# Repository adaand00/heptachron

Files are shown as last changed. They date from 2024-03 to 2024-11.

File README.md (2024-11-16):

```
    __  ____________  _________   ________  ______  ____  _   __
   / / / / ____/ __ \/_  __/   | / ____/ / / / __ \/ __ \/ | / /
  / /_/ / __/ / /_/ / / / / /| |/ /   / /_/ / /_/ / / / /  |/ / 
 / __  / /___/ ____/ / / / ___ / /___/ __  / _, _/ /_/ / /|  /  
/_/ /_/_____/_/     /_/ /_/  |_\____/_/ /_/_/ |_|\____/_/ |_/   
```                                                                
## Heptachron - 7 segment LED wrist watch
Latest prototype:


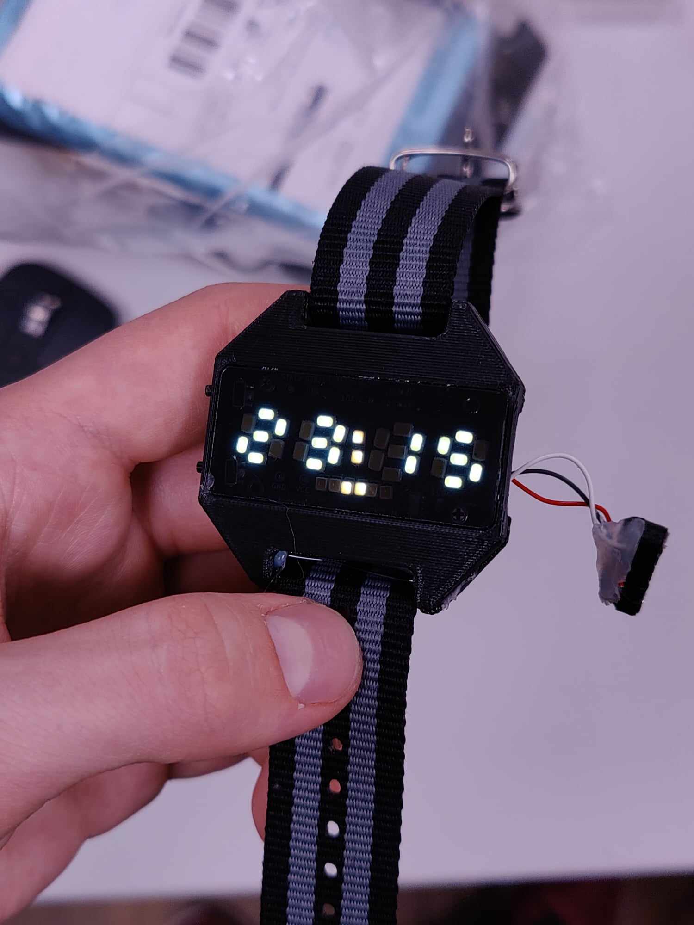
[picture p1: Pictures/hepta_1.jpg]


### Concepts and ideas
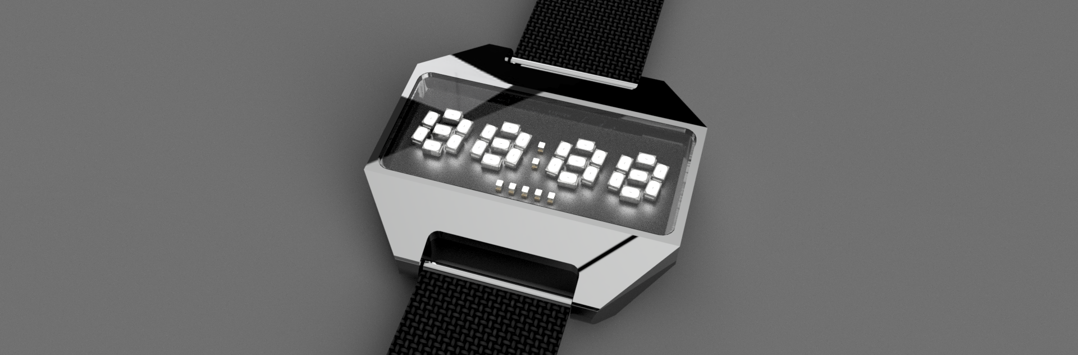
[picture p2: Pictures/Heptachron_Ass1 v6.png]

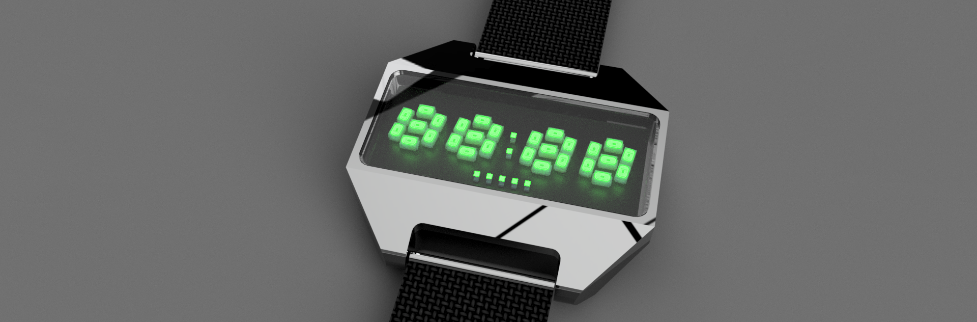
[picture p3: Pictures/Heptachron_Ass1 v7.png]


### Features
 - [x] 4 digits (hours and minutes)
 - [x] Seconds displayed in binary (6 bits)
 - [x] Always-on display
 - [x] Rechargeable battery
 - [x] Magnetic charger
 - [ ] Long battery life
 - [x] Megatron
 - [x] Not waterproof
 - [ ] Very accurate

### Contributors
Adam Anderson: Electronics, programming

Gustav Abrahamsson: Electronics, mechanical design

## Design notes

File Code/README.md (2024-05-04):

Functions:

 - View time / Set time
 - View battery / turn off
 - View brightness / set brightness
 - (View alarm / set alarm)
 - (View 24H/12H mode / set 24H/12H mode)

Use `NEXT` button to go to next function. Then press `SET` button to interact
with function. If no button is pressed for some time, the time will be displayed
again. Hold both buttons to turn off.

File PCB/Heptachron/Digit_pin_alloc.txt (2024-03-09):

CS:n  -   Current sink 'n', one for each digit       [CATHODE]
                                                              
SW:n  -   Switch power source, one for each segment  [ANODE]  
               SW1: A, SW2: B, ..., SW7: G                    

                          ┌─┬───┐                             
                          │◄│A  │                             
                          └─┴───┘                             
                   ┌───┐           ┌─▲─┐                      
                   │   │           ├───┤                      
                   │ F │           │ B │                      
                   ├───┤           │   │                      
                   └─▼─┘  ┌─┬───┐  └───┘                      
                          │◄│G  │                             
                   ┌───┐  └─┴───┘  ┌─▲─┐                      
                   │   │           ├───┤                      
                   │ E │           │ C │                      
                   ├───┤           │   │                      
                   └─▼─┘           └───┘                      
                          ┌─┬───┐                             
                          │◄│D  │                             
                          └─┴───┘

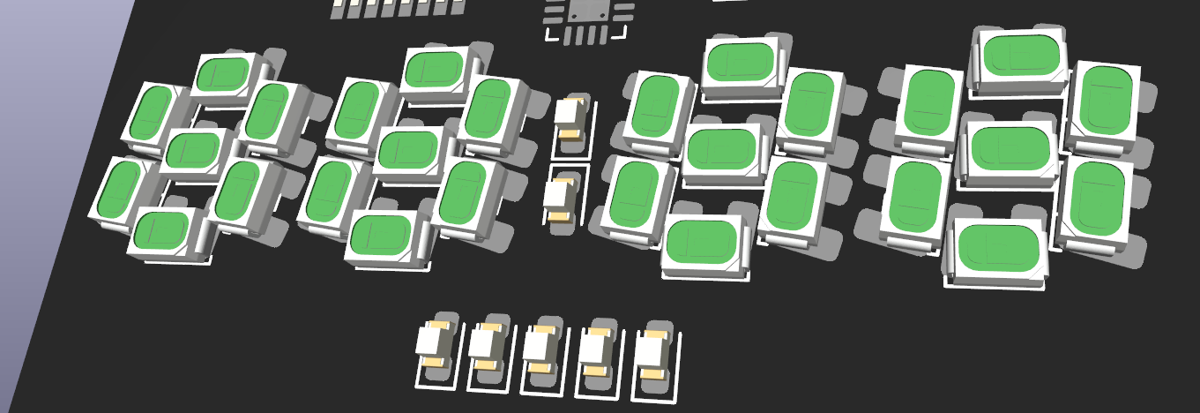
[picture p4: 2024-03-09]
Pictures/PCB_concept.png

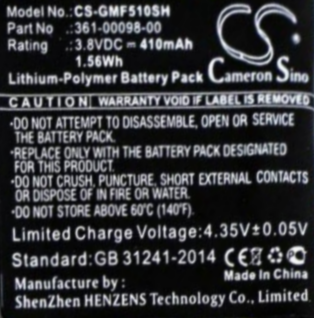
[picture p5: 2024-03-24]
Pictures/Battery_label.png

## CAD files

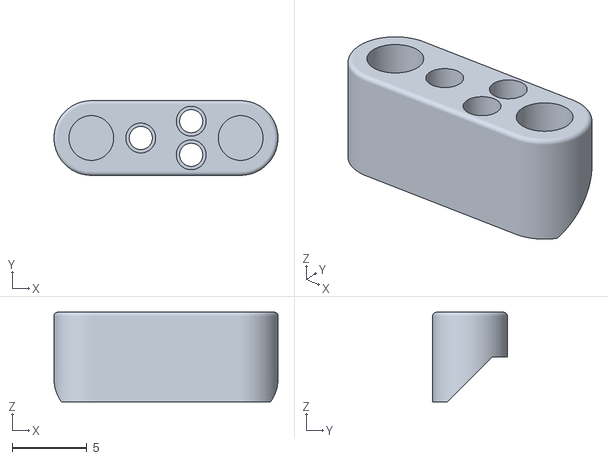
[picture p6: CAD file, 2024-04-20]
CAD/Pre/Female_heptachronnector.stl
15.0 x 5.00 x 6.00

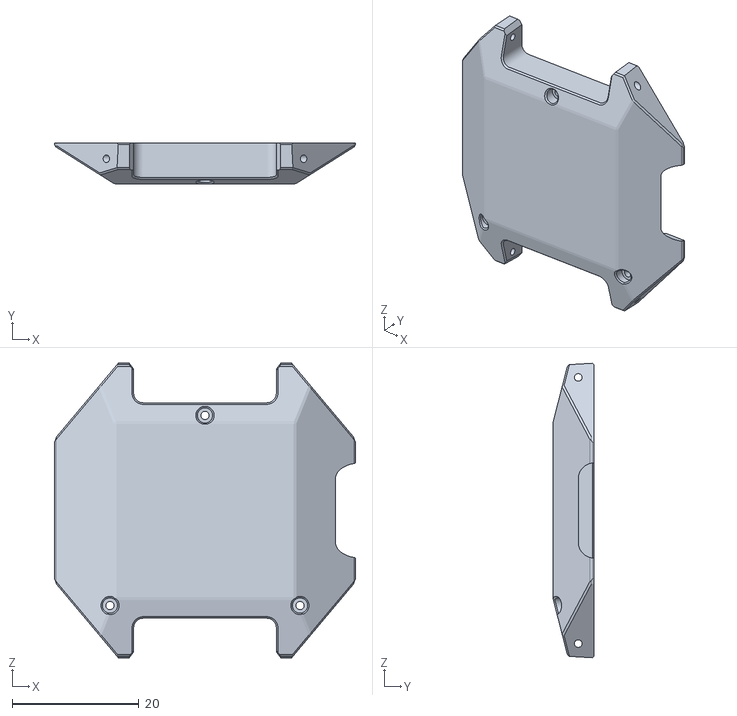
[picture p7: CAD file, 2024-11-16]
CAD/v2/Case_bottom.stl
47.5 x 6.50 x 46.5

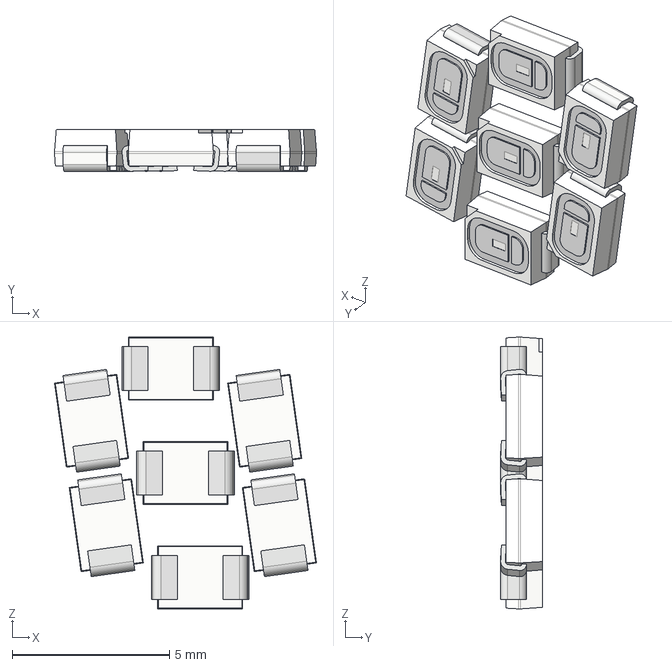
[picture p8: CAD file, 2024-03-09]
PCB/3D_Files/Cree_LED/Cree_Digit.step
8.32 x 1.32 x 8.63 mm
Cree_Green_PLCC2 x 7

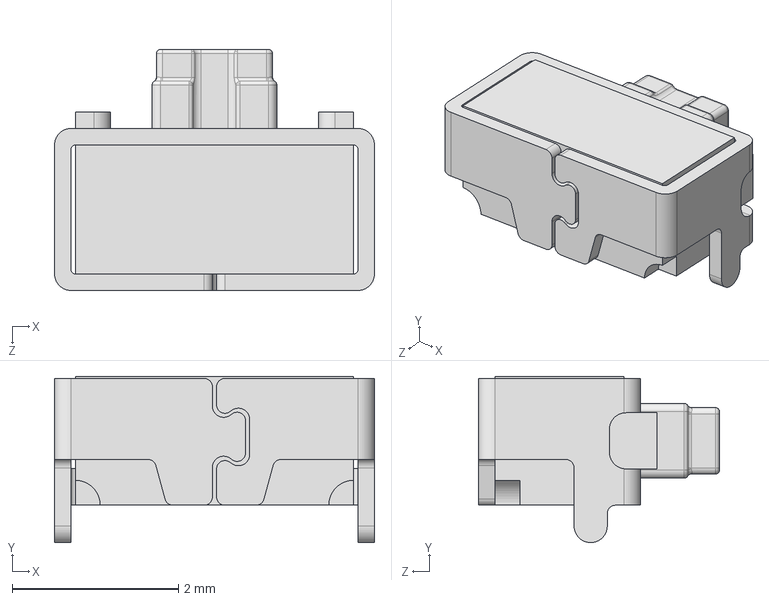
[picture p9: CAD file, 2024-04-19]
PCB/Heptachron/Component_files/TL6340AF160Q (tiny button)/TL6340AF160Q.step
3.85 x 2.00 x 2.90 mm

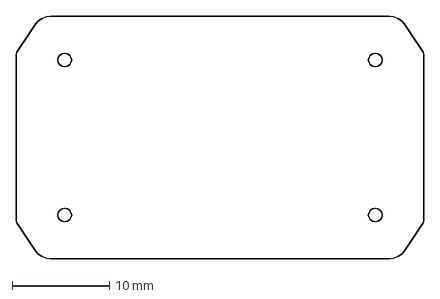
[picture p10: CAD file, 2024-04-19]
PCB/Heptachron/Edge_cuts/Heptachron_edge_cuts.dxf
42.0 x 25.0 mm

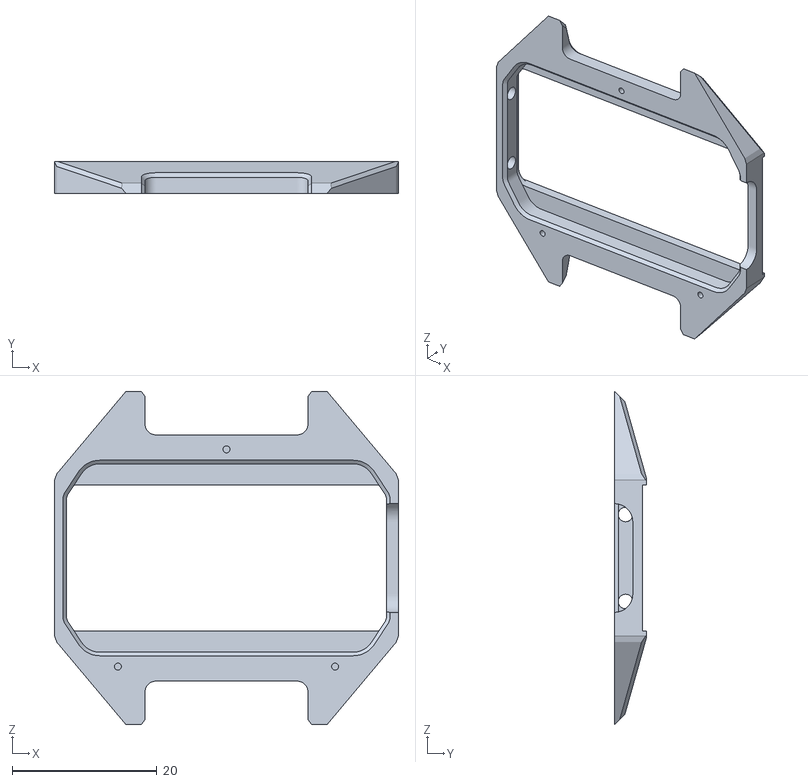
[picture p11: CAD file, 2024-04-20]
CAD/Pre/Case_top.stl
47.5 x 4.37 x 46.0

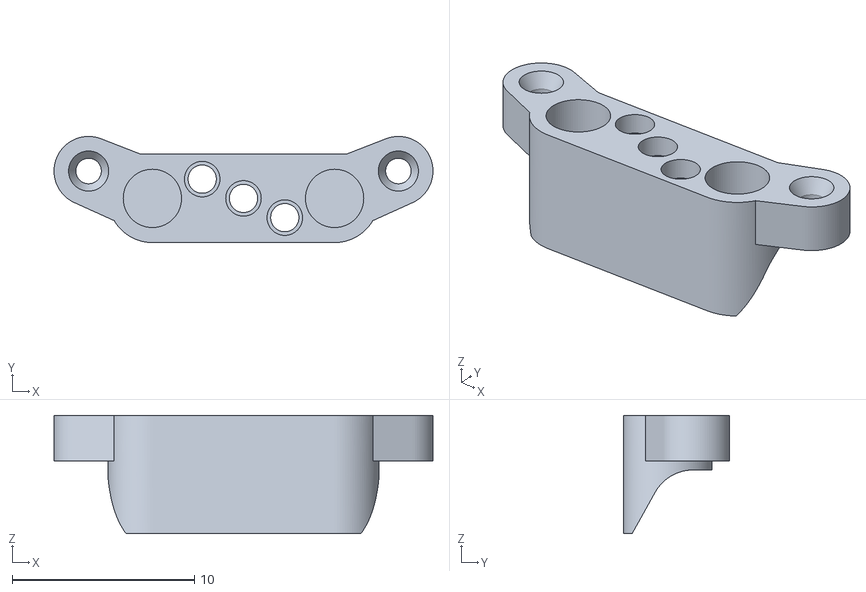
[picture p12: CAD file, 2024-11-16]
CAD/v2/Female_heptachronnector.stl
20.8 x 5.82 x 6.50

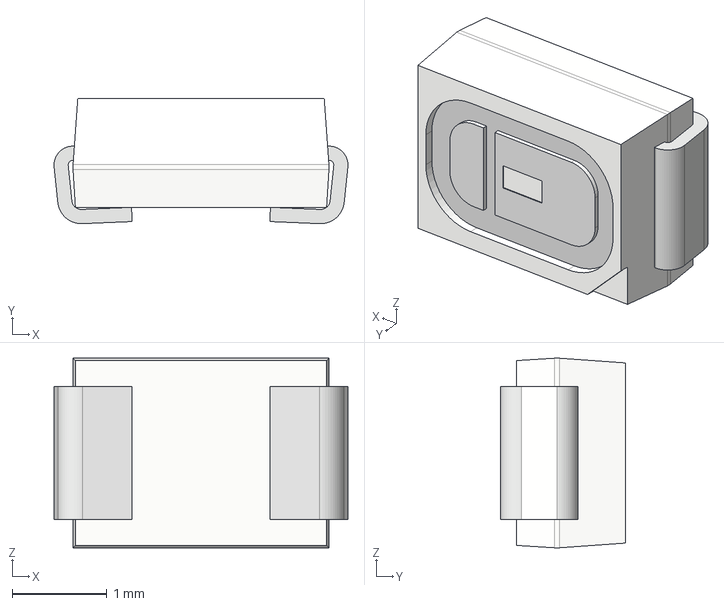
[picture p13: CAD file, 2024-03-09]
PCB/3D_Files/Cree_LED/Cree_Green_PLCC2 v14.step
3.10 x 1.32 x 2.00 mm

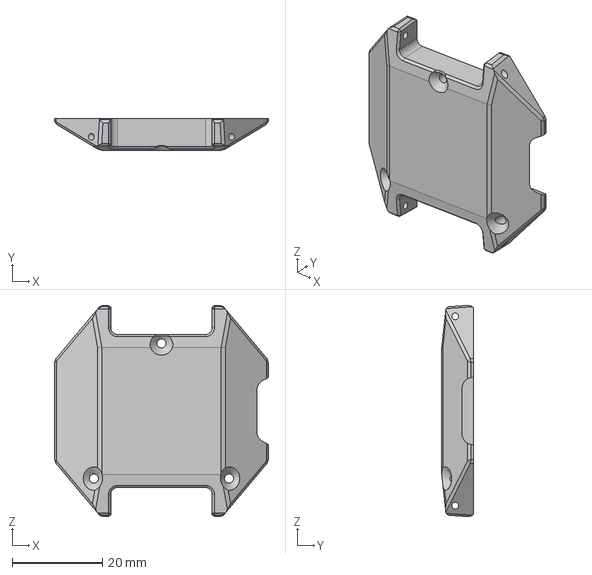
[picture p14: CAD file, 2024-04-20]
CAD/Pre/Case_bottom v32.step
47.5 x 7.00 x 46.9 mm

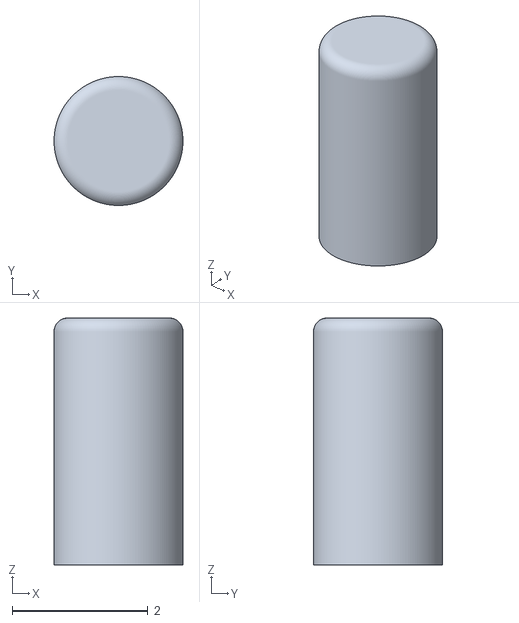
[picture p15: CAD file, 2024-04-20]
CAD/Pre/Button_head.stl
1.90 x 1.90 x 3.64

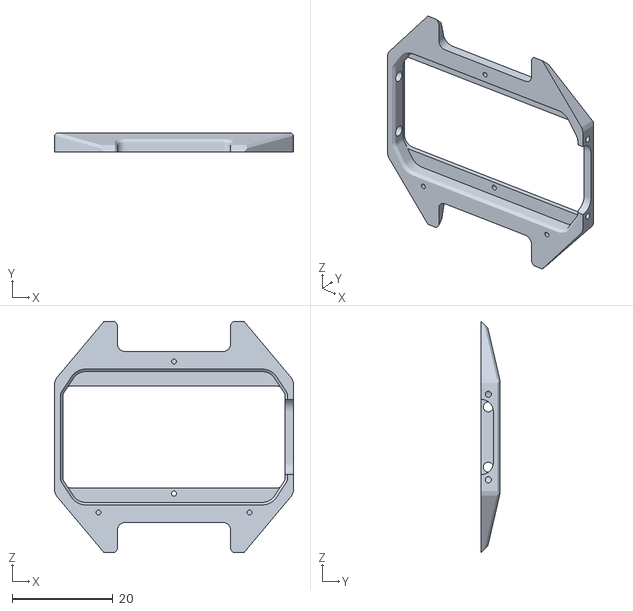
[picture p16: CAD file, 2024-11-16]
CAD/v2/Case_top.stl
47.5 x 3.85 x 46.0

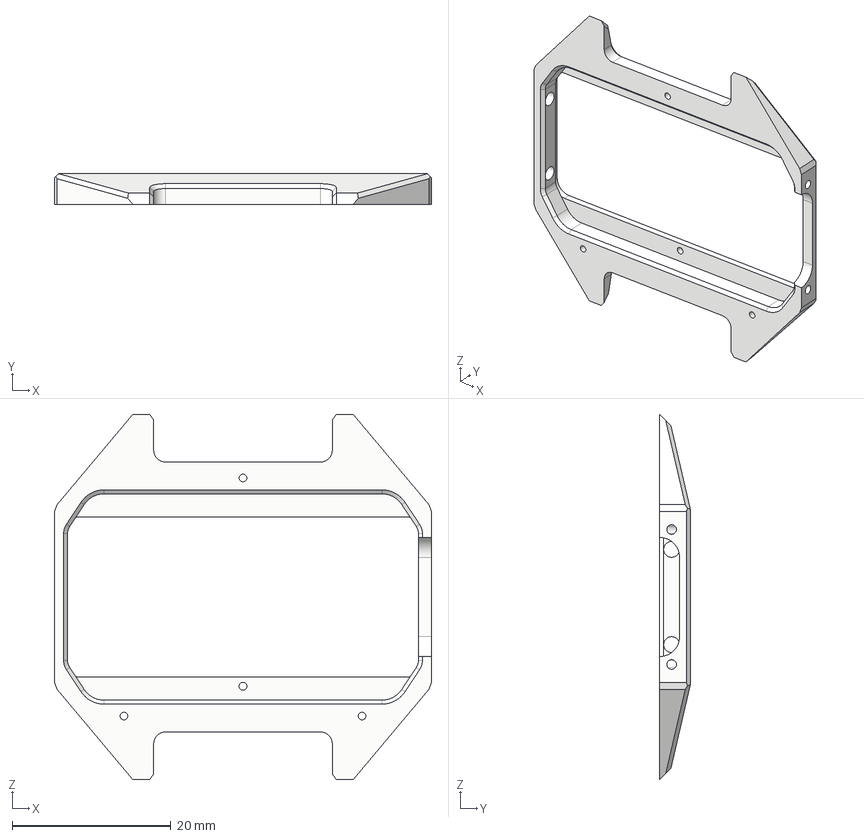
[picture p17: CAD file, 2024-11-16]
CAD/v2/Case_top v53.step
47.5 x 3.85 x 46.0 mm

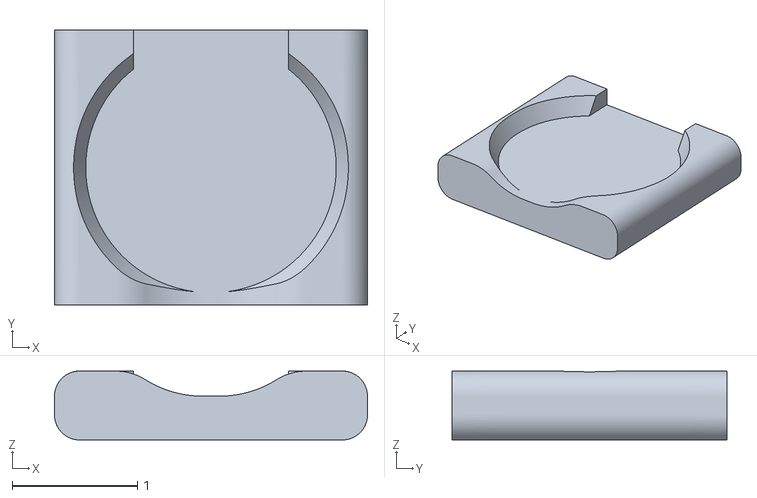
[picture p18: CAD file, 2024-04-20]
CAD/Pre/Button_base.stl
2.50 x 2.20 x 0.55

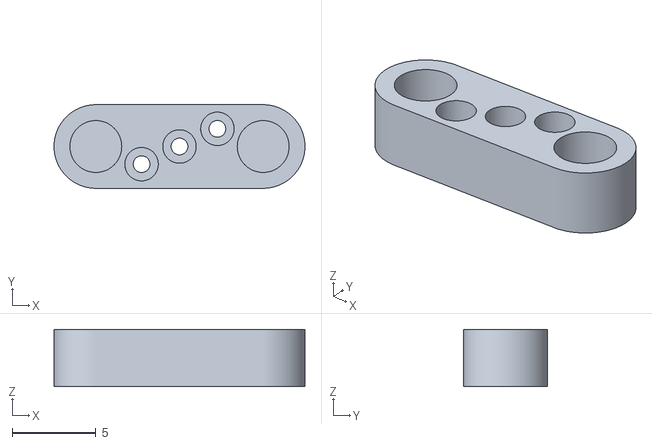
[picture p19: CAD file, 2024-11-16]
CAD/v2/Male heptachronnector.stl
15.0 x 5.00 x 3.42

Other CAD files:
CAD/v2/Case_bottom v52.step
PCB/3D_Files/Cree_LED/Heptachron_LED v5_BRIGHT.step
PCB/3D_Files/Cree_LED/Heptachron_LED v5_BRIGHT_V2.step
CAD/Pre/Case_bottom.stl
CAD/Pre/Case_top v36.step
CAD/Pre/Heptachron_window.dxf
CAD/Pre/Male heptachronnector.stl
CAD/v1/Button_base.stl
CAD/v1/Case_bottom.stl
CAD/v1/Case_top v50.stl
CAD/v1/Female_heptachronnector.stl
CAD/v1/Hepta_spacer.stl
CAD/v1/Male heptachronnector.stl
CAD/v2/Button_base.stl
CAD/v2/Hepta_spacer v4.stl

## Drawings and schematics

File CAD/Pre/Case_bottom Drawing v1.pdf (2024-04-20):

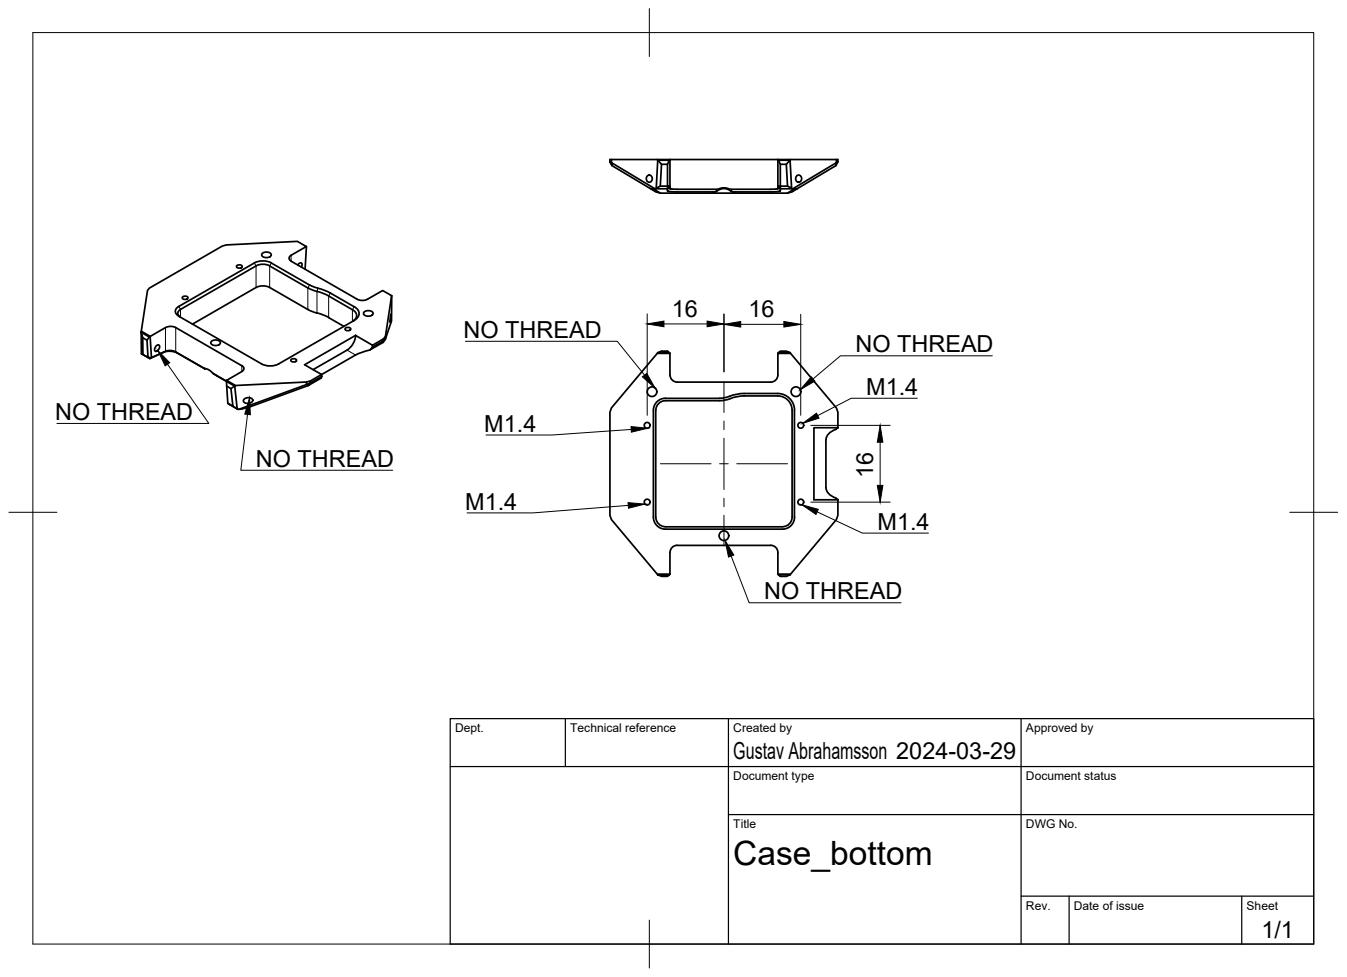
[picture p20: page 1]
NO THREAD

NO THREAD

Dept. | Technical reference | Created by Gustav Abrahamsson 2024-03-29 | Approved by

Document type | Document status

Title Case_bottom | DWG No.

Rev. | Date of issue | Sheet 1/1

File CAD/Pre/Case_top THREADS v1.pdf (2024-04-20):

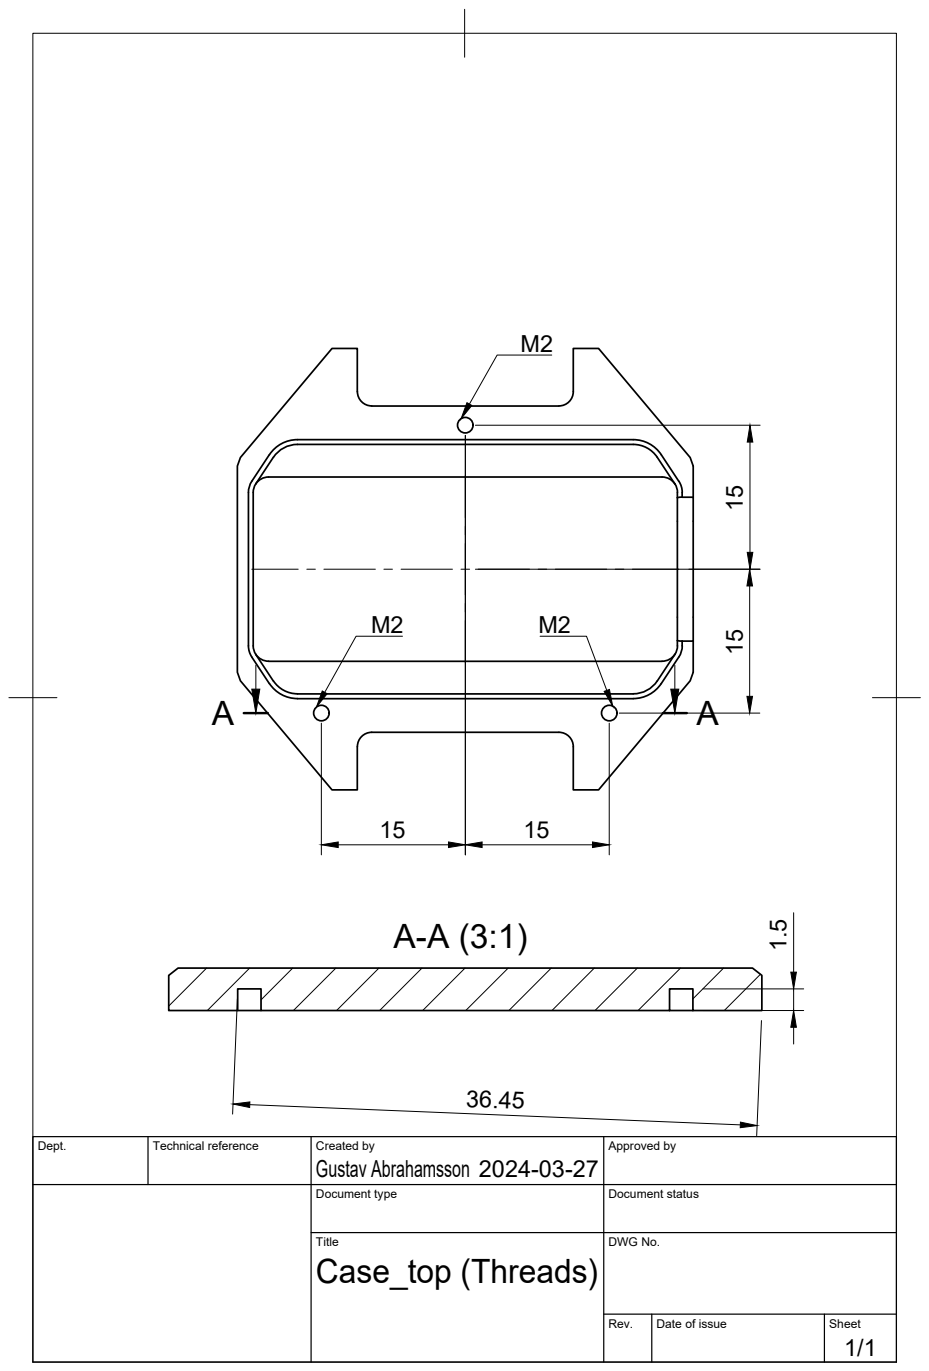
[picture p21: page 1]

Dept. | Technical reference | Created by Gustav Abrahamsson 2024-03-27 | Approved by

Document type | Document status

Title Case_top (Threads) | DWG No.

Rev. | Date of issue | Sheet 1/1

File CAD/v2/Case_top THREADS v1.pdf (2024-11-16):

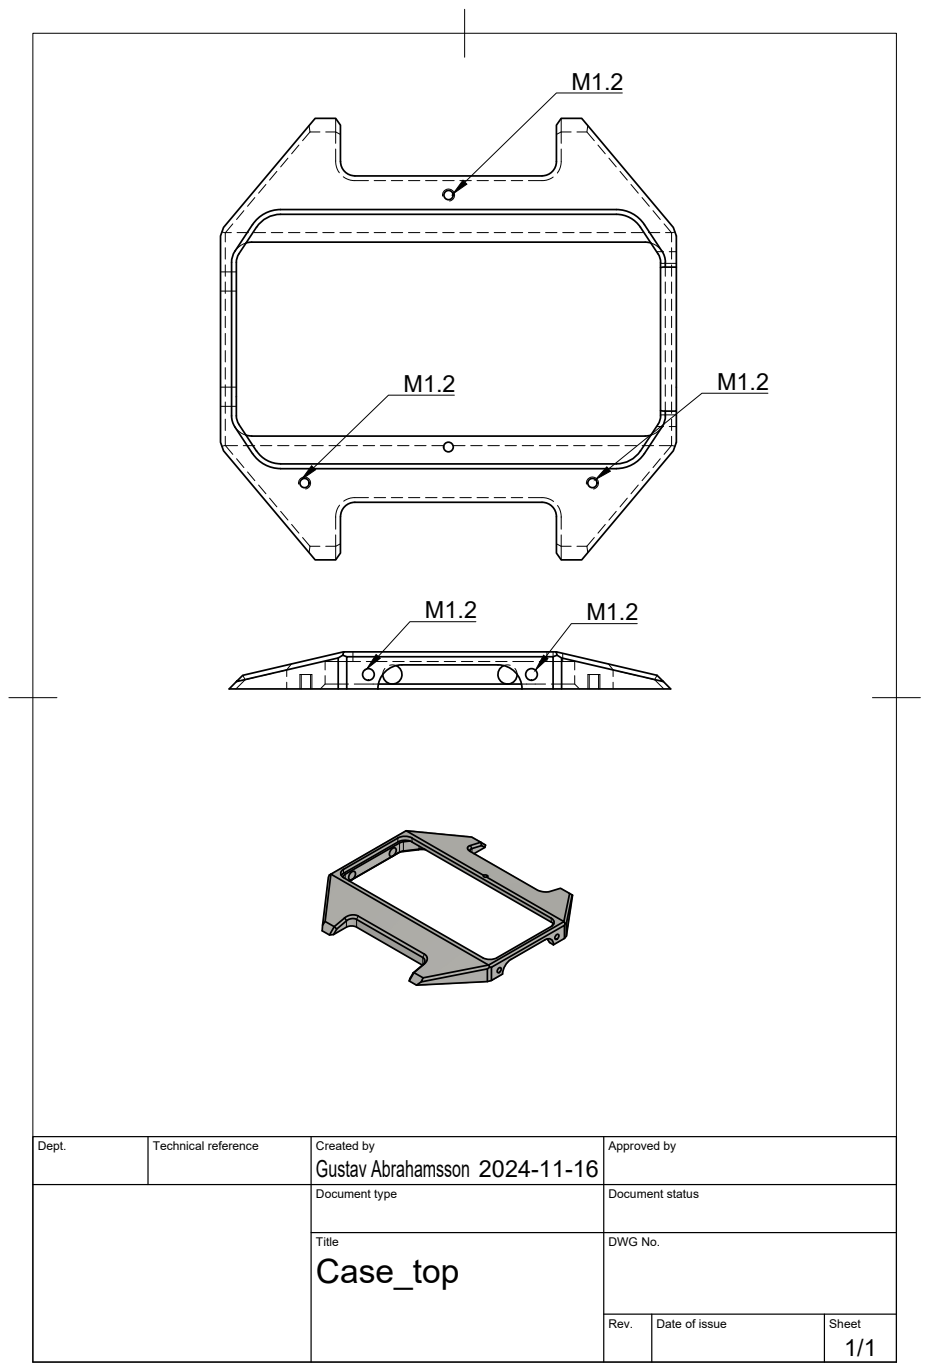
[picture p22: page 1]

Dept. | Technical reference | Created by Gustav Abrahamsson 2024-11-16 | Approved by

Document type | Document status

Title Case_top | DWG No.

Rev. | Date of issue | Sheet 1/1

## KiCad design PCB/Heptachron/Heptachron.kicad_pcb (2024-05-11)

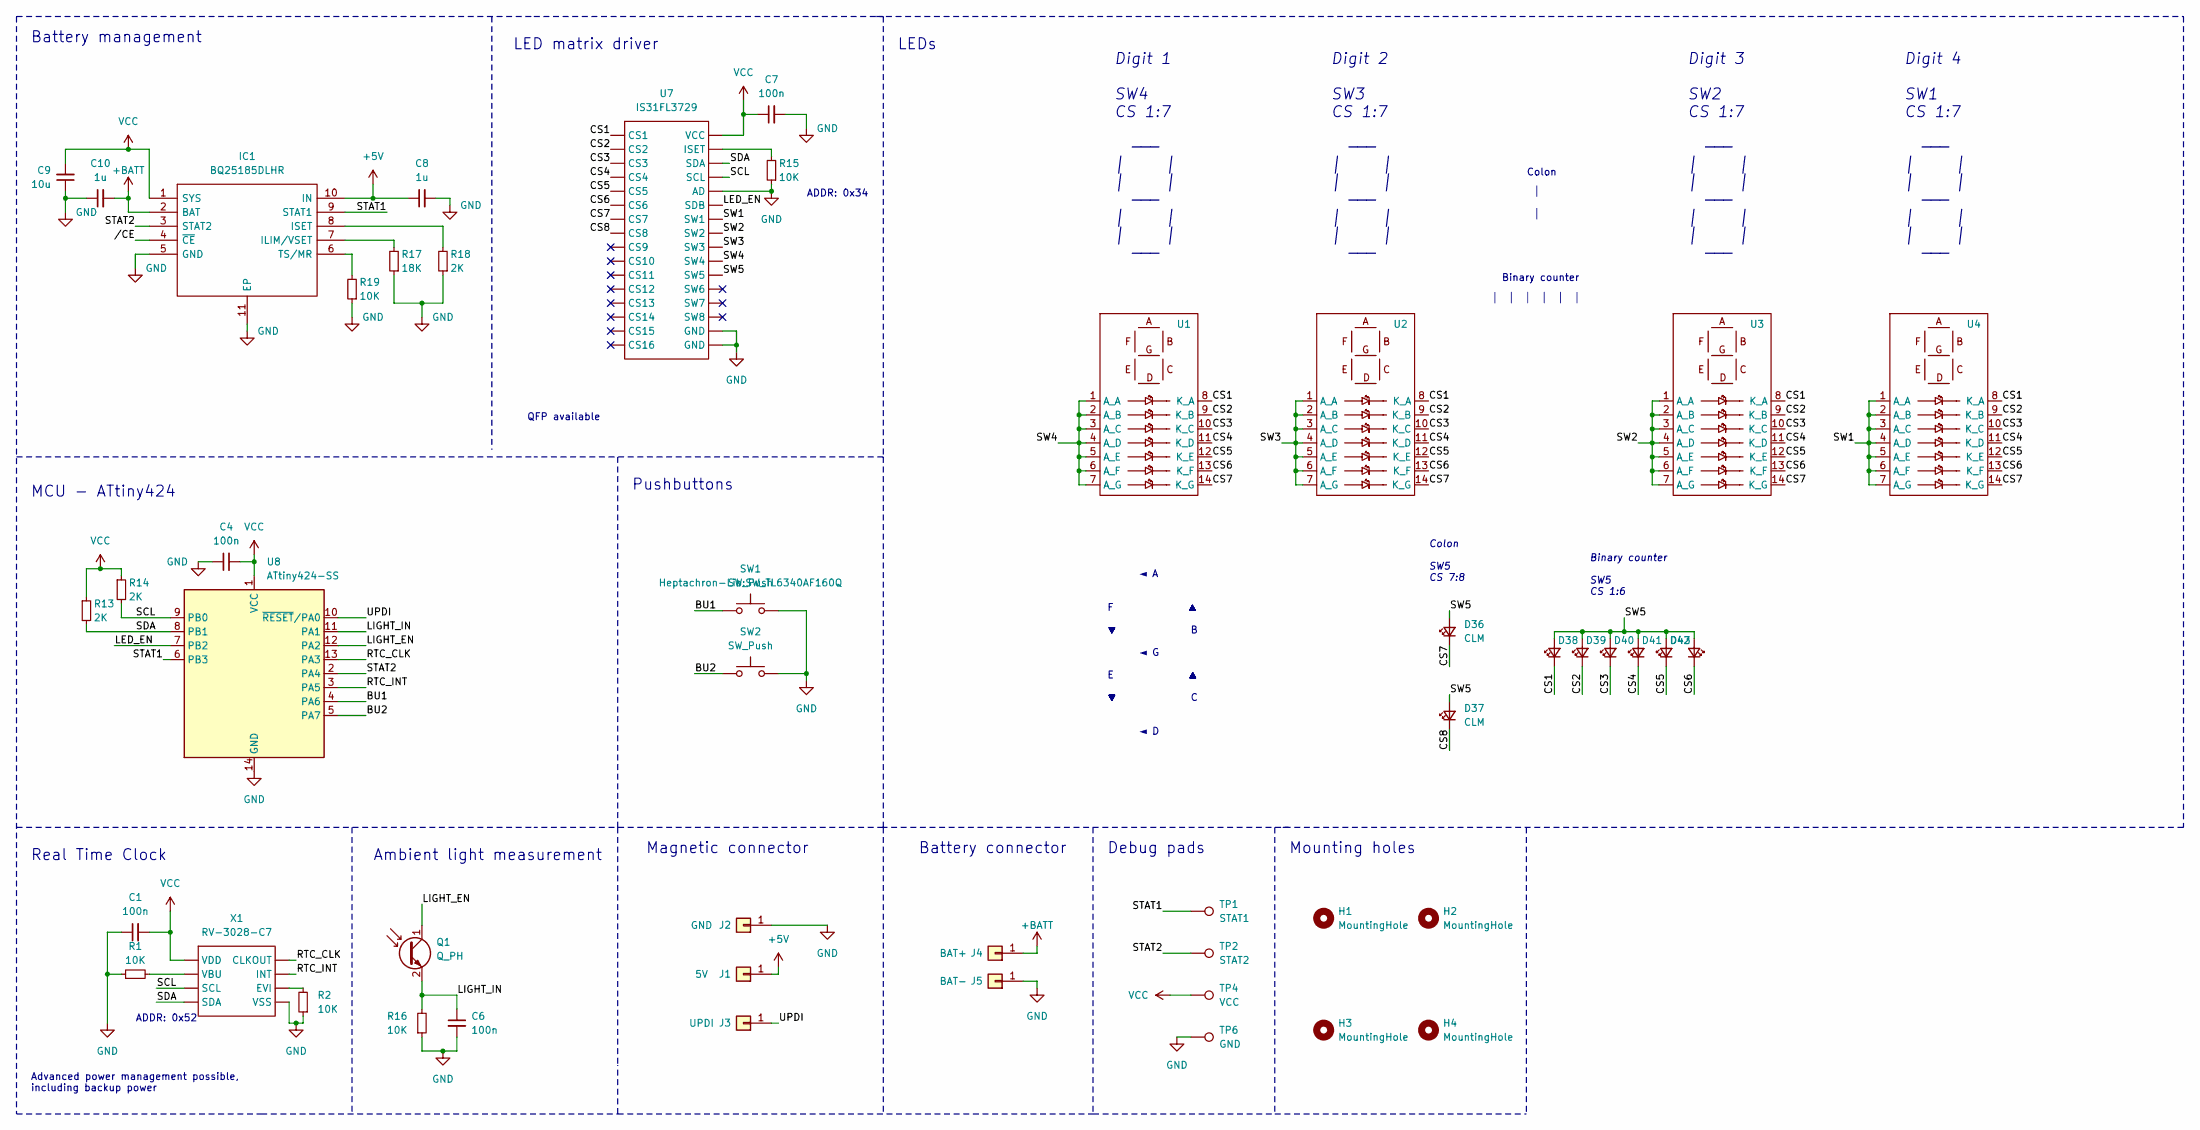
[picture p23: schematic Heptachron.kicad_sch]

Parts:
C1, C4, C6, C7: 100n; C_0603_1608Metric
C8, C10: 1u; C_0805_2012Metric
C9: 10u; C_0805_2012Metric
D36, D37: CLM; LED_0603_1608Metric
D38, D39, D40, D41, D42, D43: LED_0603_1608Metric
H1, H2, H3, H4: MountingHole; MountingHole_1.5mm_PAD
IC1: BQ25185DLHR; SON40P220X200X80-11N; Mouser Part Number 595-BQ25185DLHR
J1: 5V; SolderWirePad_1x01_SMD_1x2mm
J2: GND; SolderWirePad_1x01_SMD_1x2mm
J3: UPDI; SolderWirePad_1x01_SMD_1x2mm
J4: BAT+; SolderWirePad_1x01_SMD_1x2mm
J5: BAT-; SolderWirePad_1x01_SMD_1x2mm
Q1: Q_PH; LED_0603_1608Metric
R1, R2, R15, R16, R19: 10K; R_0603_1608Metric
R13, R14, R18: 2K; R_0603_1608Metric
R17: 18K; R_0603_1608Metric
SW1, SW2: SW_Push; SW_TL6340AF160Q
TP1: STAT1; TestPoint_Pad_D1.0mm
TP2: STAT2; TestPoint_Pad_D1.0mm
TP4: VCC; TestPoint_Pad_D1.0mm
TP6: GND; TestPoint_Pad_D1.0mm
U1, U2, U3, U4: 7-SEGMENT_NEW
U7: IS31FL3729; TQFP-32_7x7mm_P0.8mm
U8: ATtiny424-SS; SOIC-14_3.9x8.7mm_P1.27mm
X1: RV-3028-C7

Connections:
+5V: C8.1, IC1.10 (IN), J1.1
+BATT: C10.2, IC1.2 (BAT), J4.1
/BU1: SW1.1, U8.4 (PA6)
/BU2: SW2.1, U8.5 (PA7)
/CS1: D38.1 (K), U1.8 (K_A), U2.8 (K_A), U3.8 (K_A), U4.8 (K_A), U7.30 (CS1)
/CS2: D39.1 (K), U1.9 (K_B), U2.9 (K_B), U3.9 (K_B), U4.9 (K_B), U7.31 (CS2)
/CS3: D40.1 (K), U1.10 (K_C), U2.10 (K_C), U3.10 (K_C), U4.10 (K_C), U7.32 (CS3)
/CS4: D41.1 (K), U1.11 (K_D), U2.11 (K_D), U3.11 (K_D), U4.11 (K_D), U7.1 (CS4)
/CS5: D42.1 (K), U1.12 (K_E), U2.12 (K_E), U3.12 (K_E), U4.12 (K_E), U7.2 (CS5)
/CS6: D43.1 (K), U1.13 (K_F), U2.13 (K_F), U3.13 (K_F), U4.13 (K_F), U7.3 (CS6)
/CS7: D36.1 (K), U1.14 (K_G), U2.14 (K_G), U3.14 (K_G), U4.14 (K_G), U7.4 (CS7)
/CS8: D37.1 (K), U7.5 (CS8)
/LED_EN: U7.29 (SDB), U8.7 (PB2)
/LIGHT_EN: Q1.1 (C), U8.12 (PA2)
/LIGHT_IN: C6.1, Q1.2 (E), R16.2, U8.11 (PA1)
/RTC_CLK: U8.13 (PA3), X1.1 (CLKOUT)
/RTC_INT: U8.3 (PA5), X1.2 (INT)
/SCL: R14.2, U7.27 (SCL), U8.9 (PB0), X1.3 (SCL)
/SDA: R13.2, U7.26 (SDA), U8.8 (PB1), X1.4 (SDA)
/STAT1: IC1.9 (STAT1), TP1.1, U8.6 (PB3)
/STAT2: IC1.3 (STAT2), TP2.1, U8.2 (PA4)
/SW1: U4.1 (A_A), U4.2 (A_B), U4.3 (A_C), U4.4 (A_D), U4.5 (A_E), U4.6 (A_F), U4.7 (A_G), U7.22 (SW1)
/SW2: U3.1 (A_A), U3.2 (A_B), U3.3 (A_C), U3.4 (A_D), U3.5 (A_E), U3.6 (A_F), U3.7 (A_G), U7.21 (SW2)
/SW3: U2.1 (A_A), U2.2 (A_B), U2.3 (A_C), U2.4 (A_D), U2.5 (A_E), U2.6 (A_F), U2.7 (A_G), U7.20 (SW3)
/SW4: U1.1 (A_A), U1.2 (A_B), U1.3 (A_C), U1.4 (A_D), U1.5 (A_E), U1.6 (A_F), U1.7 (A_G), U7.19 (SW4)
/SW5: D36.2 (A), D37.2 (A), D38.2 (A), D39.2 (A), D40.2 (A), D41.2 (A), D42.2 (A), D43.2 (A), U7.18 (SW5)
/UPDI: J3.1, U8.10 (~RESET/PA0)
//CE: IC1.4 (~CE)
GND: C1.1, C4.1, C6.2, C7.2, C8.2, C9.1, C10.1, IC1.5 (GND), IC1.11 (EP), J2.1, J5.1, R1.1, R2.1, R15.1, R16.1, R17.1, R18.1, R19.1, SW1.2, SW2.2, TP6.1, U7.9 (GND), U7.24 (GND), U7.28 (AD), U8.14 (GND), X1.5 (VSS)
unnamed: IC1.7 (ILIM/VSET), R17.2
unnamed: IC1.8 (ISET), R18.2
unnamed: IC1.6 (TS/MR), R19.2
unnamed: R15.2, U7.25 (ISET)
unnamed: R2.2, X1.8 (EVI)
unnamed: R1.2, X1.6 (VBU)
VCC: C1.2, C4.2, C7.1, C9.2, IC1.1 (SYS), R13.1, R14.1, TP4.1, U7.23 (VCC), U8.1 (VCC), X1.7 (VDD)

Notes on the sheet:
Digit 3 SW2 CS 1:7 ─── │ │ │ │ ─── │ │ │ │ ───
Advanced power management possible, including backup power
│ │
Pushbuttons
Digit 2 SW3 CS 1:7 ─── │ │ │ │ ─── │ │ │ │ ───
◄ A F ▲ ▼ B ◄ G E ▲ ▼ C ◄ D
ADDR: 0x34
Real Time Clock
LED matrix driver
Ambient light measurement
QFP available
Magnetic connector
Mounting holes
│ │ │ │ │ │
Battery management
LEDs
Colon
Binary counter
Colon SW5 CS 7:8
Debug pads
Digit 1 SW4 CS 1:7 ─── │ │ │ │ ─── │ │ │ │ ───
ADDR: 0x52
Binary counter SW5 CS 1:6
Battery connector
MCU - ATtiny424
Digit 4 SW1 CS 1:7 ─── │ │ │ │ ─── │ │ │ │ ───

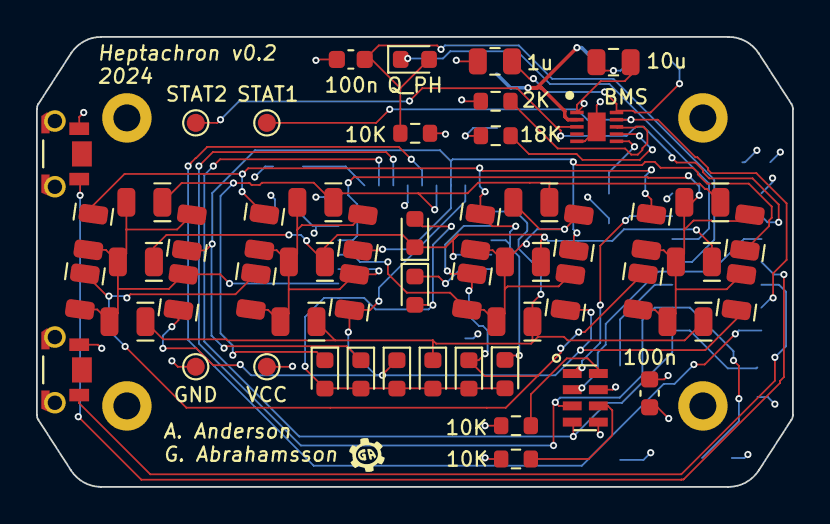
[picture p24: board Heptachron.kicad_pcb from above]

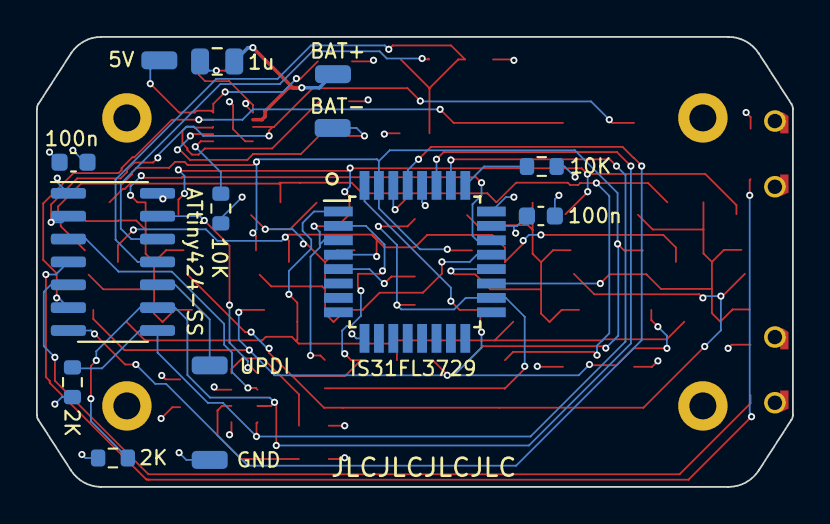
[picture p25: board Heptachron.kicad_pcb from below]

Board: 4 copper layers, 42.0 x 25.0 mm, 48 parts (14 on the bottom side), 35 nets.

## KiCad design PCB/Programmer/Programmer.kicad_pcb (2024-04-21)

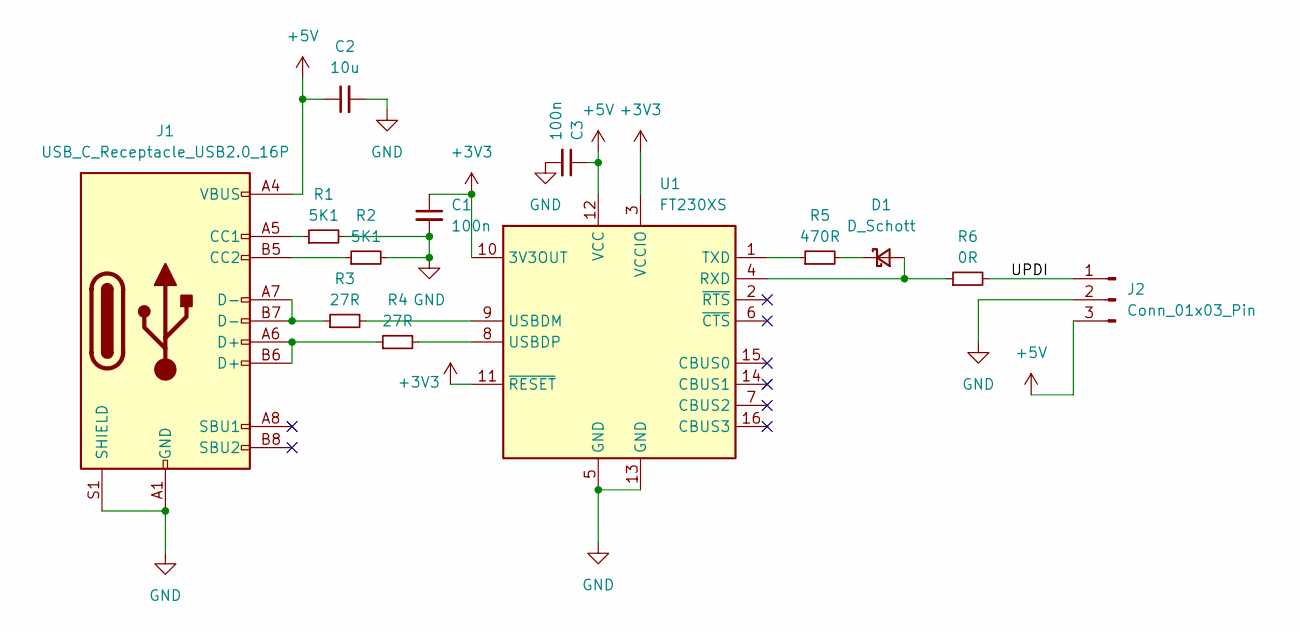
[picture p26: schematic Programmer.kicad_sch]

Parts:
C1, C3: 100n; C_0603_1608Metric
C2: 10u; C_0805_2012Metric
D1: D_Schott; D_SOD-323_HandSoldering
J1: USB_C_Receptacle_USB2.0_16P; USB_C_Receptacle_HRO_TYPE-C-31-M-12
J2: Conn_01x03_Pin; PinHeader_1x03_P2.54mm_Vertical
R1, R2: 5K1; R_0603_1608Metric
R3, R4: 27R; R_0603_1608Metric
R5: 470R; R_0603_1608Metric
R6: 0R; R_0603_1608Metric
U1: FT230XS; SSOP-16_3.9x4.9mm_P0.635mm

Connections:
+3V3: C1.1, U1.3 (VCCIO), U1.10 (3V3OUT), U1.11 (~RESET)
+5V: C2.1, C3.1, J1.A4 (VBUS), J1.A9 (VBUS), J1.B4 (VBUS), J1.B9 (VBUS), J2.3, U1.12 (VCC)
/UPDI: J2.1, R6.2
GND: C1.2, C2.2, C3.2, J1.A1 (GND), J1.A12 (GND), J1.B1 (GND), J1.B12 (GND), J1.S1 (SHIELD), J2.2, R1.2, R2.2, U1.5 (GND), U1.13 (GND)
unnamed: D1.2 (A), R6.1, U1.4 (RXD)
unnamed: D1.1 (K), R5.2
unnamed: J1.A5 (CC1), R1.1
unnamed: J1.B5 (CC2), R2.1
unnamed: J1.A6 (D+), J1.B6 (D+), R4.1
unnamed: J1.A7 (D-), J1.B7 (D-), R3.1
unnamed: R5.1, U1.1 (TXD)
unnamed: R3.2, U1.9 (USBDM)
unnamed: R4.2, U1.8 (USBDP)

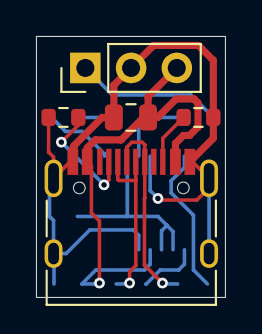
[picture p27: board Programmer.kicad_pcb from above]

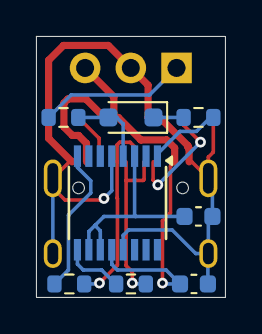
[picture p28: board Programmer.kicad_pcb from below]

Board: 2 copper layers, 10.5 x 14.5 mm, 13 parts (8 on the bottom side), 13 nets.

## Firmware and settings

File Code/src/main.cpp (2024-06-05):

#include <Arduino.h>
#include "Wire.h"
#include "avr/sleep.h"

#include "LedMatrix.h"
#include "RV3028C7.h"

#define SCL PIN_PB0
#define SDA PIN_PB1

#define LED_EN PIN_PB2

#define RTC_CLK PIN_PA3
#define RTC_INT PIN_PA5

#define LIGHT_IN PIN_PA1
#define LIGHT_EN PIN_PA2

#define STAT1 PIN_PB3
#define STAT2 PIN_PA4

#define BU1 PIN_PA6
#define BU2 PIN_PA7

#define LED_ADDR 0x34
#define RTK_ADDR 0x52

LedMatrix mat(&Wire);
RV3028C7 rtc;

typedef enum screens {
  TIME,
  BAT,
  // BRIGHTNESS,
  SCREENS_MAX,
} screen_t;

screen_t screen;
uint8_t edit = false;

uint8_t idle_count;

int bat = 0;
int light = 0;
volatile int i = 0;

// Overwrite TCA0 init since we do not use analogWrite(), saves some flash 
void init_TCA0() { };

void setup() {
  // Setup sleep mode
  set_sleep_mode(SLEEP_MODE_PWR_DOWN);
  sleep_enable();
  
  // Setup pins
  pinMode(LIGHT_EN, OUTPUT);
  digitalWriteFast(LIGHT_EN, LOW);
  pinMode(LIGHT_IN, INPUT);

  pinMode(BU1, INPUT_PULLUP);
  PORTA_PIN6CTRL |= PORT_ISC_BOTHEDGES_gc;

  pinMode(BU2, INPUT_PULLUP);
  PORTA_PIN7CTRL |= PORT_ISC_BOTHEDGES_gc;

  pinMode(LED_EN, OUTPUT);
  digitalWriteFast(LED_EN, HIGH);

  //pinMode(PGOOD, INPUT_PULLUP);
  //pinMode(RX, INPUT_PULLUP);
  //pinMode(TX, INPUT_PULLUP);

  // Clock pin interrupts
  pinMode(RTC_CLK, INPUT);
  PORTA_PIN3CTRL |= PORT_ISC_BOTHEDGES_gc;

  // Set fixed adc reference
  analogReference(INTERNAL1V024);
  // Disable ADC before sleep, brings system from 100 uA to 10 uA deep sleep.
  ADC0.CTRLA &= ~ADC_ENABLE_bm;

  // I2C 
  Wire.begin();
  Wire.setClock(400000);

  // LED matrix driver
  mat.begin();

  // RTC 
  rtc.begin(Wire);
  rtc.disableClockOutput();
  delay(1000);
  rtc.enableClockOutput(CLKOUT_1HZ);

  // init state
  screen = TIME;
}

ISR(PORTA_PORT_vect){
  int f = VPORTA_INTFLAGS;

  if(f == 1<<6){
    // Button 1
    VPORTA_INTFLAGS |= 1<<6;
  }
  if(f == 1<<7){
    // Button 2
    VPORTA_INTFLAGS |= 1<<7;
  }
  if(f == 1<<3){
    // RTC 
    i++;
    VPORTA_INTFLAGS |= 1<<3;
  }
}

void loop() {
  // Waits until pin change interrupt
  // Either RTC tick or button press
  sleep_cpu(); 
  // Increment wakeup count

  
  //Enable ADC after being woken up
  ADC0.CTRLA |= ADC_ENABLE_bm;
  // Read battery voltage, int v = 1024*VDD/10
  bat = analogRead(ADC_VDDDIV10);

  /*
  if(bat < 370){
    state = BUVLO;
  }
  */

  // Start phototransistor 
  digitalWriteFast(LIGHT_EN, HIGH);
  delay(2);

  // Read phototransistor
  light = analogRead(LIGHT_IN);
  digitalWriteFast(LIGHT_EN, LOW);
  // Turn off ADC
  ADC0.CTRLA &= ~ADC_ENABLE_bm;

  //mat.ShowBytes(255, 255, 255, 255, 255);
  
  // Read buttons
  bool b1 = !digitalReadFast(BU1);
  bool b2 = !digitalReadFast(BU2);

  // b1 goes to next screen;
  if(!edit && b1){
    screen = (screen_t) ((screen+1) % SCREENS_MAX);
  }

  switch (screen)
  {
  case TIME:
    // Read time and update LEDs
    rtc.updateTime();
    uint8_t h = rtc.getDateTimeComponent(DATETIME_HOUR);
    uint8_t m = rtc.getDateTimeComponent(DATETIME_MINUTE);
    uint8_t s = rtc.getDateTimeComponent(DATETIME_SECOND);

    // Go to next edit
    if(b2){
      edit = (edit+1)%3;
    }
    
    if(edit==1){
      // Edit minutes
      m=(m+b1)%60;
      rtc.setDateTimeComponent(DATETIME_MINUTE, m);
      rtc.synchronize();
      rtc.setDateTimeComponent(DATETIME_SECOND, 0);
      rtc.synchronize();
      
      // Blink minutes
      if(i%2 == 0){
        m = 255;
      }
      
    }else if(edit==2){
      // Edit hours 
      h=(h+b1)%24;
      rtc.setDateTimeComponent(DATETIME_HOUR, h);
      rtc.synchronize();
      rtc.setDateTimeComponent(DATETIME_SECOND, 0);
      rtc.synchronize();

      if(i%2 == 0){
        h = 255;
      }
    }

    mat.ShowTime(h, m, s, i%2);
    break;

  case BAT:
    uint8_t t = 0;
    mat.ShowBytes(0b01111100,0b01110111,0b01111000,0,t);

    if(b1){
      // Toggle LEDs on/off
      digitalWriteFast(LED_EN, !digitalReadFast(LED_EN));
    }
    break;

  default:
    break;
  }
  


}

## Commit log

2024-02-22 Start PCB
    [Heptachron.kicad_pcb, Heptachron.kicad_sch]
2024-02-23 More PCB work
    [Heptachron.kicad_sch]
2024-03-07 LEDs and more
    [Heptachron.kicad_pcb, Heptachron.kicad_sch]
2024-03-09 Continue schematic
    [7-Segment-Cree-PLCC2.kicad_sch, Heptachron.kicad_pcb, Heptachron.kicad_sch]
2024-03-09 Continue schematic, symbols & footprints for digits
    [7-Segment-Cree-PLCC2.kicad_pcb, 7-segment-subcircuit.kicad_pcb, 7-segment-subcircuit.kicad_sch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]
2024-03-09 PCB work and 3D modeling
    [Cree_Digit.step, Cree_Green_PLCC2 v14.step, Heptachron.kicad_pcb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]
2024-03-10 Finish test PCB [Ordered]
    [Heptachron-B_Cu.gbr, Heptachron-B_Mask.gbr, Heptachron-B_Paste.gbr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]
2024-03-21 Work on schematic
    [Heptachron.kicad_pcb, Heptachron.kicad_sch]
2024-03-24 Continue design
    [Case_bottom v12.step, Case_bottom.stl, Case_top v14.step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]
2024-03-24 Test PCB finished!
    [Heptachron-B_Cu.gbr, Heptachron-B_Mask.gbr, Heptachron-B_Paste.gbr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]
2024-04-06 Led driver code
2024-04-07 Add testing PCB [Ordered]
    [Heptachron-B_Cu.gbr, Heptachron-B_Mask.gbr, Heptachron-B_Paste.gbr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]
2024-04-16 Continue PCB
    [Heptachron.kicad_pcb, Heptachron.kicad_sch]
2024-04-18 Button inputs and 10 uA sleep!
2024-04-20 Programmer finished
    [Programmer.kicad_pcb, Programmer.kicad_sch]
2024-04-20 Add stl and step
    [Button_base.stl, Button_head.stl, Case_bottom v12.step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]
2024-04-20 PCB v0.1 [Ordered]
    [Heptachron-B_Cu.gbr, Heptachron-B_Mask.gbr, Heptachron-B_Paste.gbr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]
2024-04-21 Programmer Gerbers
    [Programmer-B_Cu.gbr, Programmer-B_Mask.gbr, Programmer-B_Paste.gbr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]
2024-05-11 PCB v0.2
    [Heptachron-B_Cu.gbr, Heptachron-B_Mask.gbr, Heptachron-B_Paste.gbr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]
2024-05-24 Add BOM and misc
    [Heptachron-B_Cu.gbr, Heptachron-B_Mask.gbr, Heptachron-B_Paste.gbr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]
2024-06-05 reverse seconds bits, blinking not working
    [main.cpp]
2024-11-16 Add v2 case and connector
    [Button_base.stl, Case_bottom v52.step, Case_bottom.stl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]
